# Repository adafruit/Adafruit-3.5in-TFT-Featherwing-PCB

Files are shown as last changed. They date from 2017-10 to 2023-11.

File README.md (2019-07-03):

## Adafruit 3.5in TFT LCD Display FeatherWing PCB

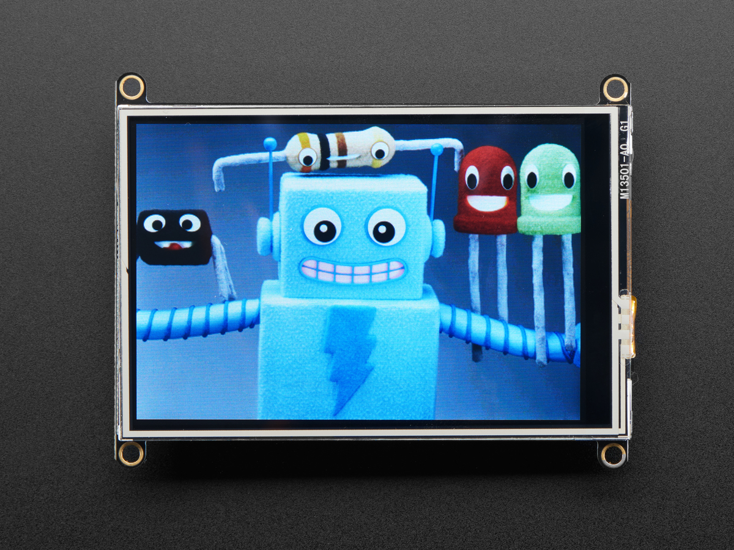
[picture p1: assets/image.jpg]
<a href="http://www.adafruit.com/products/3651"><br/>
Click here to purchase one from the Adafruit shop</a>

PCB files for the Adafruit 3.5in TFT LCD display FeatherWing. Format is EagleCAD schematic and board layout

For more details, check out the product page at
* https://www.adafruit.com/products/3651

### Description

Spice up your Feather project with a beautiful 3.5" touchscreen display shield with built in microSD card socket. This TFT display is 3.5" diagonal with a bright 6 white-LED backlight. You get a massive 480x320 pixels with individual 16-bit color pixel control. It has way more resolution than a black and white 128x64 display, and twice as much as our 2.4" TFT FeatherWing. As a bonus, this display comes with a resistive touchscreen attached to it already, so you can detect finger presses anywhere on the screen

This FeatherWing uses a SPI display, touchscreen and SD card socket. It works with any and all Feathers but given the large display it works best with our faster boards like the nRF52, ESP8266, ESP32, M0, M4, WICED, and Teensy. We also include an SPI resistive touchscreen controller so you only need one additional pin to add a high quality touchscreen controller. One more pin is used for an optional SD card that can be used for storing images for display.

This Wing comes fully assembled with dual sockets for your Feather to plug into. You get two sockets per pin so you can plug in wires if you want to connect to Feather pins. Alternatively, each pin has a large square pad on the PCB for direct soldering.

### License

Adafruit invests time and resources providing this open source design, please support Adafruit and open-source hardware by purchasing products from [Adafruit](https://www.adafruit.com)!

Designed by Limor Fried/Ladyada for Adafruit Industries.

Creative Commons Attribution/Share-Alike, all text above must be included in any redistribution. See license.txt for additional details.

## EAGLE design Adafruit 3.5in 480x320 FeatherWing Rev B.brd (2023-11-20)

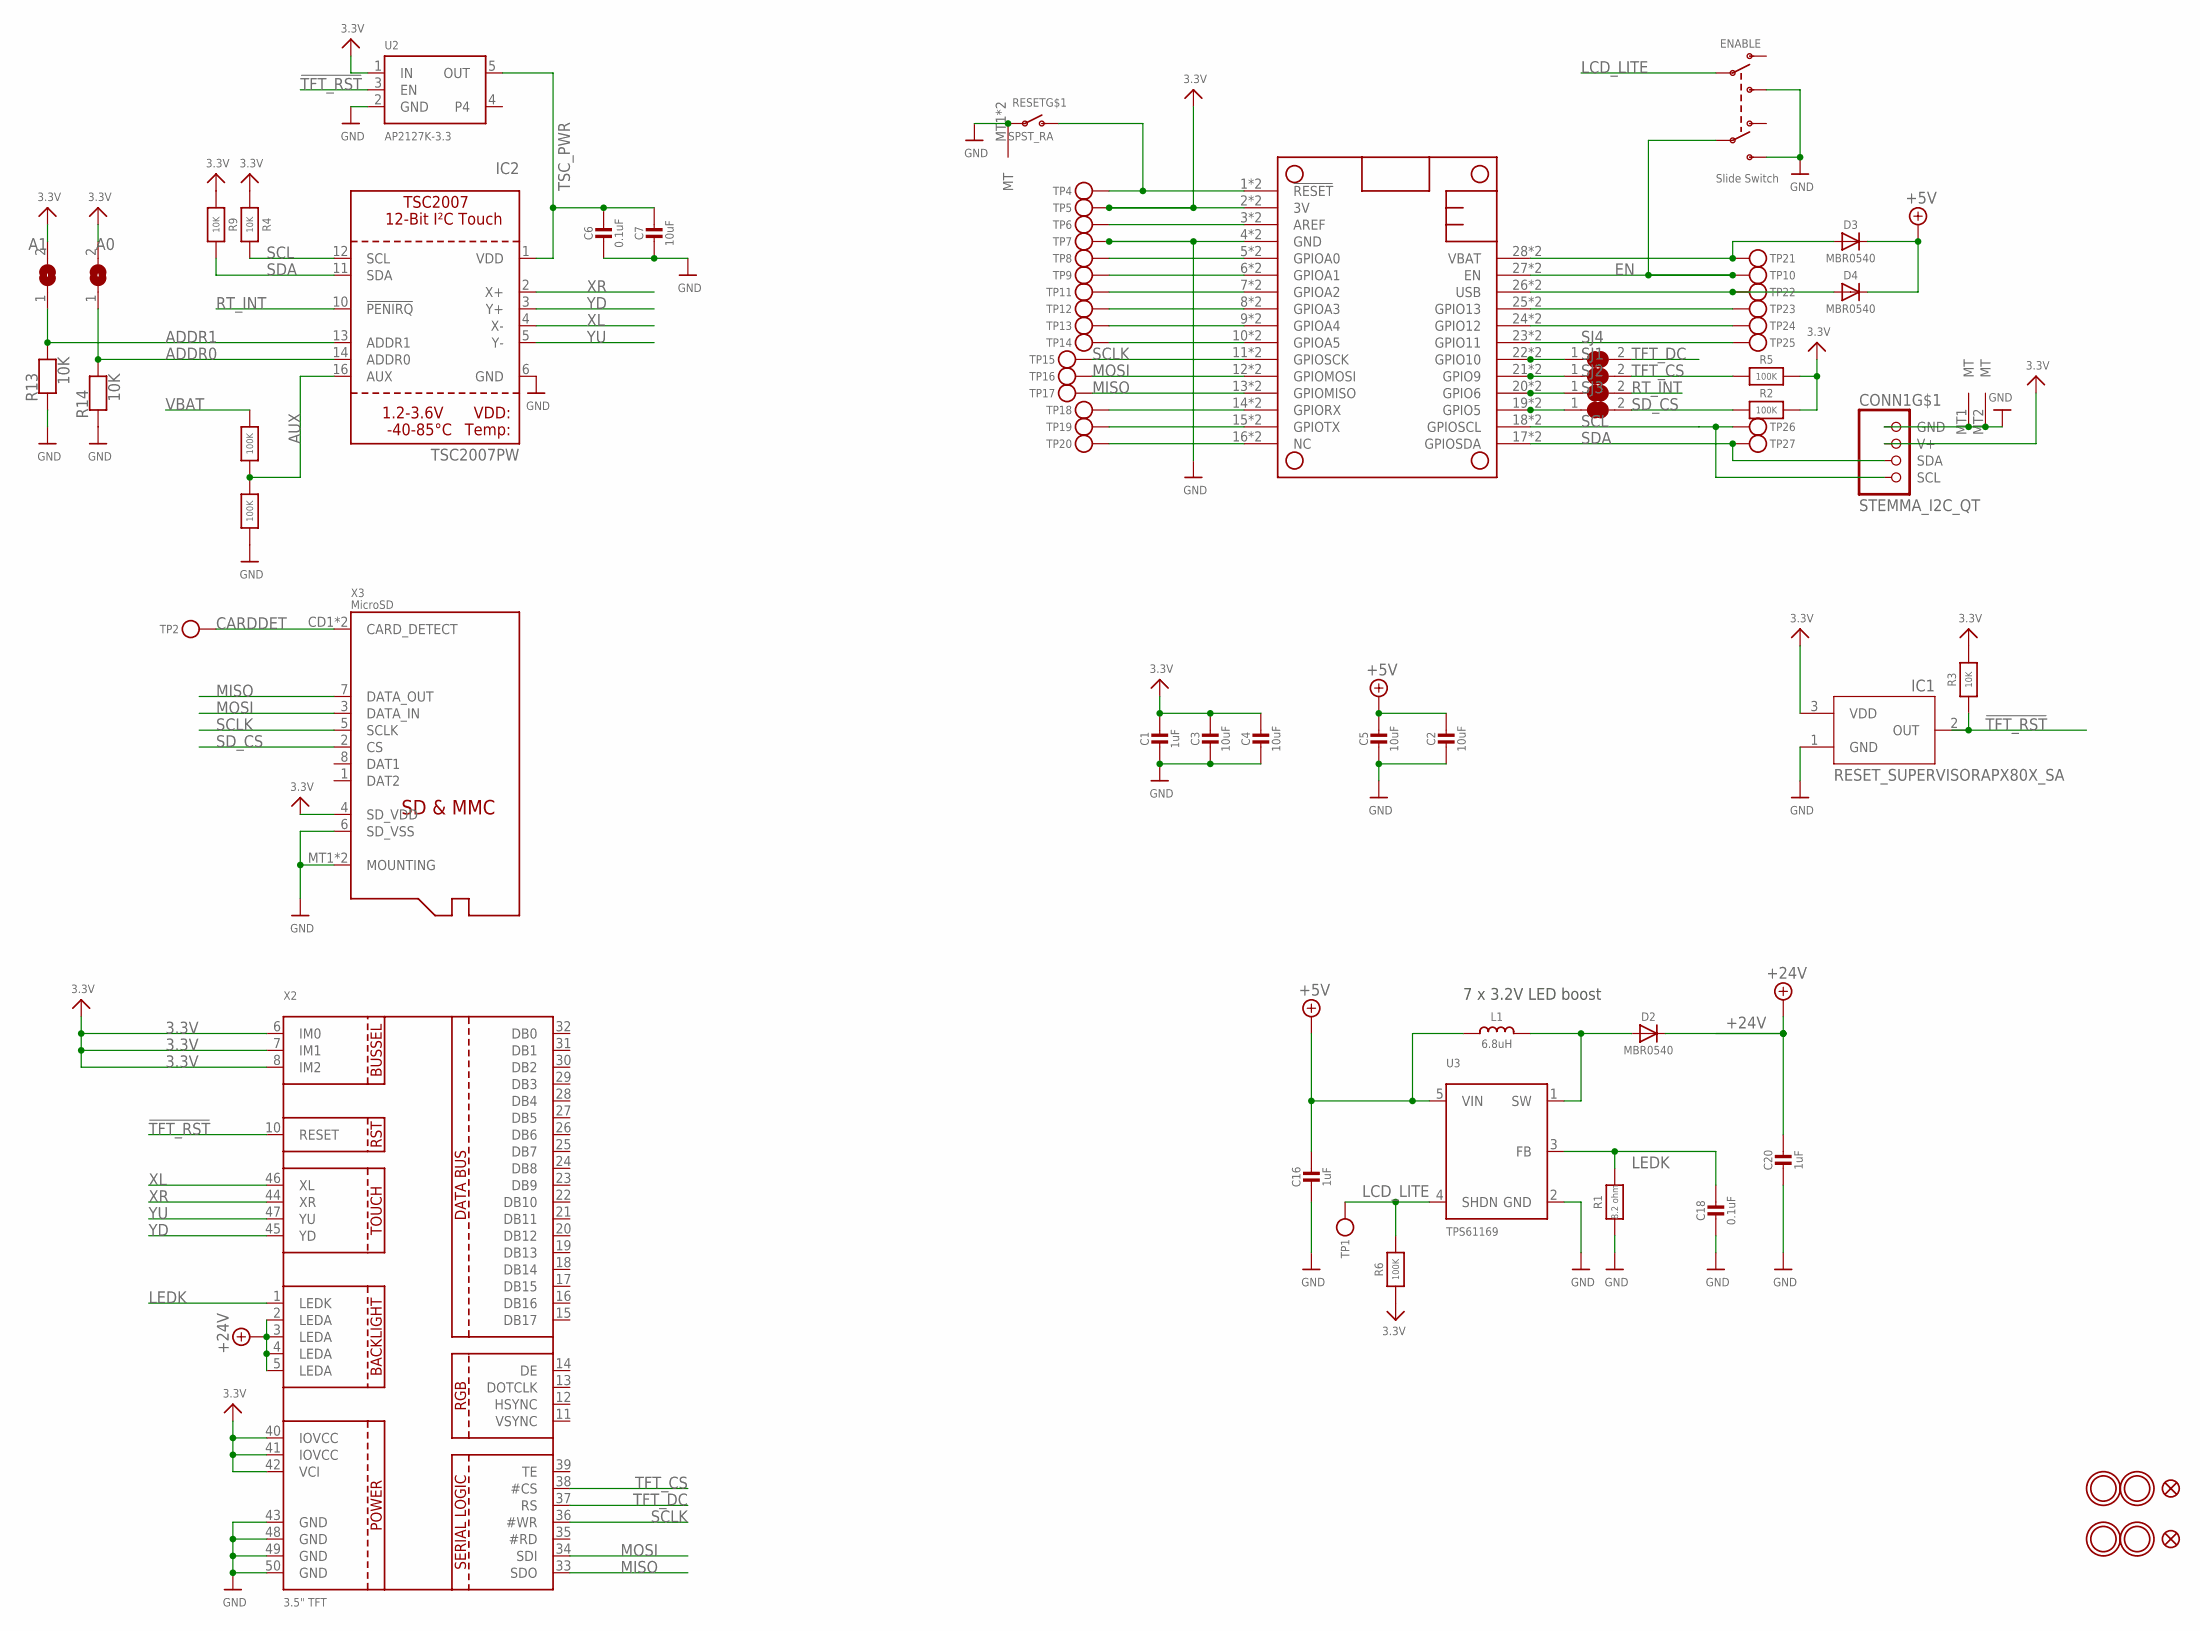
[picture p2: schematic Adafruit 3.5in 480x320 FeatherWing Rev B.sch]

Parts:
C1, C16, C20: 1uF; 0805-NO
C2, C3, C4, C5, C7: 10uF; 0805-NO
C6, C18: 0.1uF; 0603-NO
CONN1: STEMMA_I2C_QT; JST_SH4
D2, D3, D4: MBR0540; SOD-123
ENABLE: Slide Switch; EG1390
IC1: RESET_SUPERVISORAPX80X_SA; SOT23-WIDE
IC2: TSC2007PW; TSSOP16
ICSP_CLK1: A1; SOLDERJUMPER_ARROW_NOPASTE
ICSP_CLK2: A0; SOLDERJUMPER_ARROW_NOPASTE
L1: 6.8uH; INDUCTOR_5X5MM_NR5040_NOTHERMALS
MS2: FEATHERWING_SMTDUAL; FEATHERWING_SMT2
R1: 8.2 ohm; 0603-NO
R2, R5, R6, R10, R11: 100K; 0603-NO
R3, R4, R9, R13, R14: 10K; 0603-NO
RESET: SPST_RA; SPST_TACTILE_RA
SJ1, SJ2, SJ3, SJ4: SOLDERJUMPER_CLOSED; SOLDERJUMPER_CLOSEDWIRE
TP1, TP2, TP4, TP5, TP6, TP7, TP8, TP9, TP10, TP11, TP12, TP13, TP14, TP15, TP16, TP17, TP18, TP19, TP20, TP21, TP22, TP23, TP24, TP25, TP26, TP27: TESTPOINTPAD2MM; TESTPOINT_PAD_2MM
U2: AP2127K-3.3; SOT23-5
U3: TPS61169; SC70-5
U$7, U$15, U$16, U$17: MOUNTINGHOLE3.0THIN; MOUNTINGHOLE_3.0_PLATEDTHIN
U$9, U$23: FIDUCIAL_1MM
X2: 3.5" TFT; TFT_3.5IN_320X480_50PIN
X3: MicroSD; MICROSD

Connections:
3.3V: C1.1, C3.1, C4.1, CONN1.2 (V+), IC1.3 (VDD), ICSP_CLK1.2, ICSP_CLK2.2, MS2.2 (3V), MS2.2' (3V), R2.2, R3.2, R4.1, R5.2, R6.1, R9.1, TP5.P$1, U2.1 (IN), X2.6 (IM0), X2.7 (IM1), X2.8 (IM2), X2.40 (IOVCC), X2.41 (IOVCC), X2.42 (VCI), X3.4 (SD_VDD)
!RESET: MS2.1 (!RESET), MS2.1' (!RESET), RESET.2 (S), TP4.P$1
!TFT_RST: IC1.2 (OUT), R3.1, U2.3 (EN), X2.10 (RESET)
+5V: C2.1, C5.1, C16.1, D3.C, D4.C, L1.P$1 (1), U3.5 (VIN)
+24V: C20.1, D2.C, X2.2 (LEDA), X2.3 (LEDA), X2.4 (LEDA), X2.5 (LEDA)
A: MS2.5 (GPIOA0), MS2.5' (GPIOA0), TP8.P$1
ADDR0: IC2.14 (ADDR0), ICSP_CLK2.1, R14.2
ADDR1: IC2.13 (ADDR1), ICSP_CLK1.1, R13.2
AREF: MS2.3 (AREF), MS2.3' (AREF), TP6.P$1
AUX: IC2.16 (AUX), R10.1, R11.2
B: MS2.6 (GPIOA1), MS2.6' (GPIOA1), TP9.P$1
C: MS2.7 (GPIOA2), MS2.7' (GPIOA2), TP11.P$1
CARDDET: TP2.P$1, X3.CD1 (CARD_DETECT), X3.CD2 (CARD_DETECT)
D: MS2.8 (GPIOA3), MS2.8' (GPIOA3), TP12.P$1
E: MS2.9 (GPIOA4), MS2.9' (GPIOA4), TP13.P$1
EN: ENABLE.P2, MS2.27 (EN), MS2.27' (EN), TP10.P$1
F: MS2.10 (GPIOA5), MS2.10' (GPIOA5), TP14.P$1
G: MS2.16 (NC), MS2.16' (NC), TP20.P$1
GND: C1.2, C2.2, C3.2, C4.2, C5.2, C6.2, C7.2, C16.2, C18.2, C20.2, CONN1.1 (GND), CONN1.MT1 (MT), CONN1.MT2 (MT), ENABLE.S1, ENABLE.S2, IC1.1 (GND), IC2.6 (GND), MS2.4 (GND), MS2.4' (GND), R1.1, R11.1, R13.1, R14.1, RESET.1, RESET.MT1 (MT), RESET.MT2 (MT), TP7.P$1, U2.2 (GND), U3.2 (GND), X2.43 (GND), X2.48 (GND), X2.49 (GND), X2.50 (GND), X3.6 (SD_VSS), X3.MT1 (MOUNTING), X3.MT2 (MOUNTING)
H: MS2.19 (GPIO5), MS2.19' (GPIO5), SJ3.1
I: MS2.20 (GPIO6), MS2.20' (GPIO6), SJ2.1
J: MS2.21 (GPIO9), MS2.21' (GPIO9), SJ1.1
K: MS2.22 (GPIO10), MS2.22' (GPIO10), SJ4.1
L: MS2.23 (GPIO11), MS2.23' (GPIO11), TP25.P$1
LCD_LITE: ENABLE.P1, R6.2, TP1.P$1, U3.4 (SHDN)
LEDK: C18.1, R1.2, U3.3 (FB), X2.1 (LEDK)
M: MS2.24 (GPIO12), MS2.24' (GPIO12), TP24.P$1
MISO: MS2.13 (GPIOMISO), MS2.13' (GPIOMISO), TP17.P$1, X2.33 (SDO), X3.7 (DATA_OUT)
MOSI: MS2.12 (GPIOMOSI), MS2.12' (GPIOMOSI), TP16.P$1, X2.34 (SDI), X3.3 (DATA_IN)
N: MS2.25 (GPIO13), MS2.25' (GPIO13), TP23.P$1
unnamed: D2.A, L1.P$2 (2), U3.1 (SW)
RT_INT: IC2.10 (!PENIRQ), SJ2.2
RX: MS2.14 (GPIORX), MS2.14' (GPIORX), TP18.P$1
SCL: CONN1.4 (SCL), IC2.12 (SCL), MS2.18 (GPIOSCL), MS2.18' (GPIOSCL), R4.2, TP26.P$1
SCLK: MS2.11 (GPIOSCK), MS2.11' (GPIOSCK), TP15.P$1, X2.36 (#WR), X3.5 (SCLK)
SDA: CONN1.3 (SDA), IC2.11 (SDA), MS2.17 (GPIOSDA), MS2.17' (GPIOSDA), R9.2, TP27.P$1
SD_CS: R2.1, SJ3.2, X3.2 (CS)
TFT_CS: R5.1, SJ1.2, X2.38 (#CS)
TFT_DC: SJ4.2, X2.37 (RS)
TSC_PWR: C6.1, C7.1, IC2.1 (VDD), U2.5 (OUT)
TX: MS2.15 (GPIOTX), MS2.15' (GPIOTX), TP19.P$1
USB: D4.A, MS2.26 (USB), MS2.26' (USB), TP22.P$1
VBAT: D3.A, MS2.28 (VBAT), MS2.28' (VBAT), R10.2, TP21.P$1
XL: IC2.4 (X-), X2.46 (XL)
XR: IC2.2 (X+), X2.44 (XR)
YD: IC2.3 (Y+), X2.45 (YD)
YU: IC2.5 (Y-), X2.47 (YU)

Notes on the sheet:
7 x 3.2V LED boost

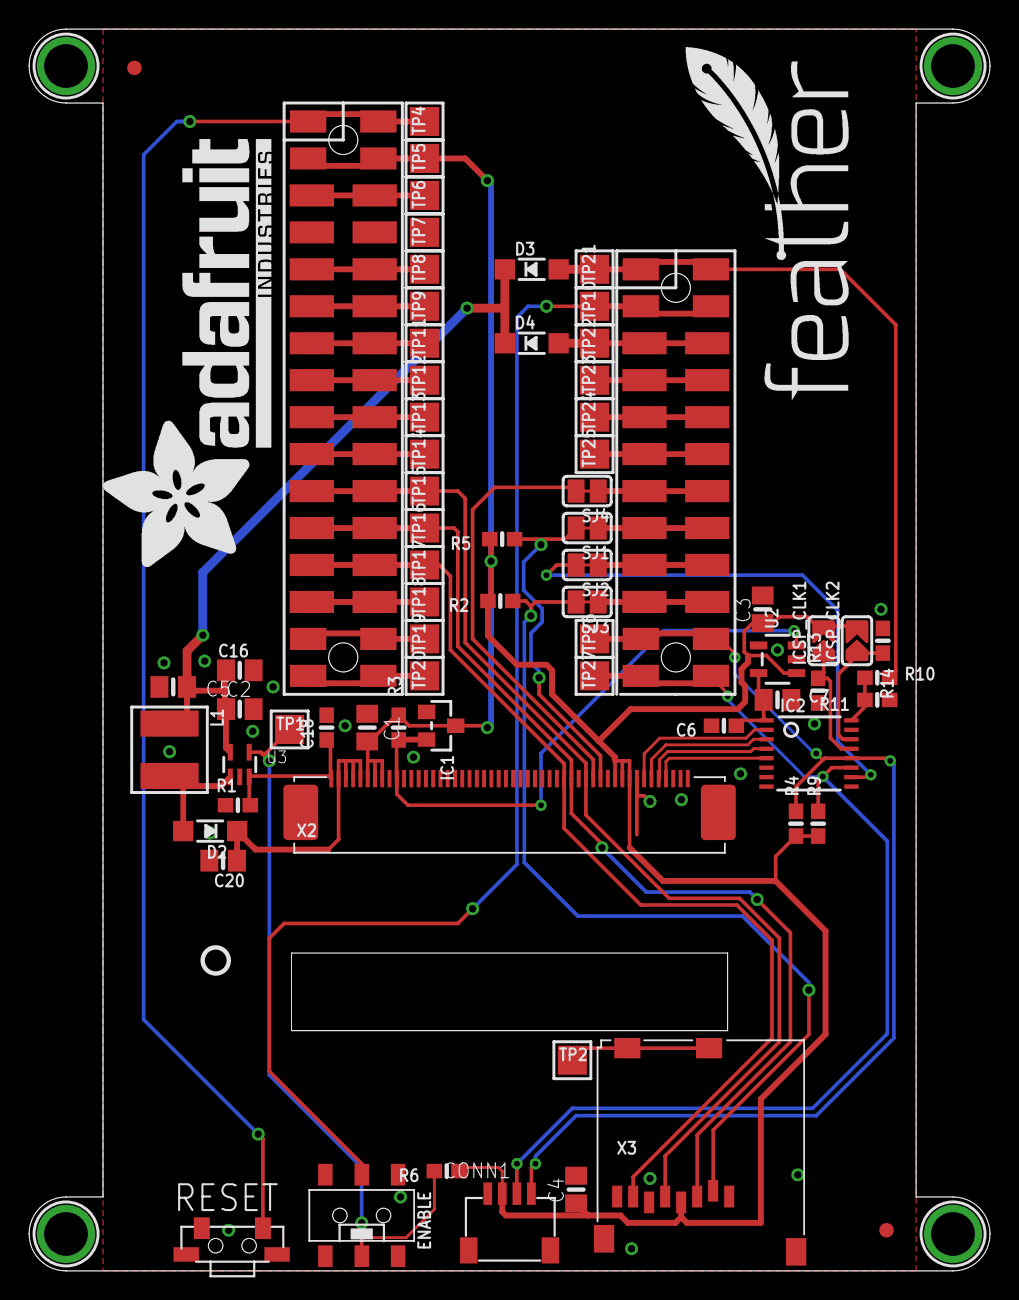
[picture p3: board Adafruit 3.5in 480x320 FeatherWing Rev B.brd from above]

Board: 2 copper layers, 66.0 x 85.3 mm, 92 parts (1 on the bottom side), 47 nets.

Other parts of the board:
PLABEL0: PLABEL0
PLABEL1: PLABEL1
PLABEL2: PLABEL2
PLABEL3: PLABEL3
PLABEL4: PLABEL4
PLABEL5: PLABEL5
PLABEL6: PLABEL6
PLABEL7: PLABEL7
PLABEL8: PLABEL8
PLABEL9: PLABEL9
PLABEL10: PLABEL10
PLABEL11: PLABEL11
PLABEL12: PLABEL12
PLABEL13: PLABEL13
PLABEL14: PLABEL14
PLABEL15: PLABEL15
U$11: FEATHERLOGO
U$19: ADAFRUIT_TEXT_30MM
U$37: PCBFEAT-REV-040
